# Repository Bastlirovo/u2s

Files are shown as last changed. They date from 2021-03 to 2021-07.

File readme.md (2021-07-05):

# USB To Serial Convertor Board

<p align="center">
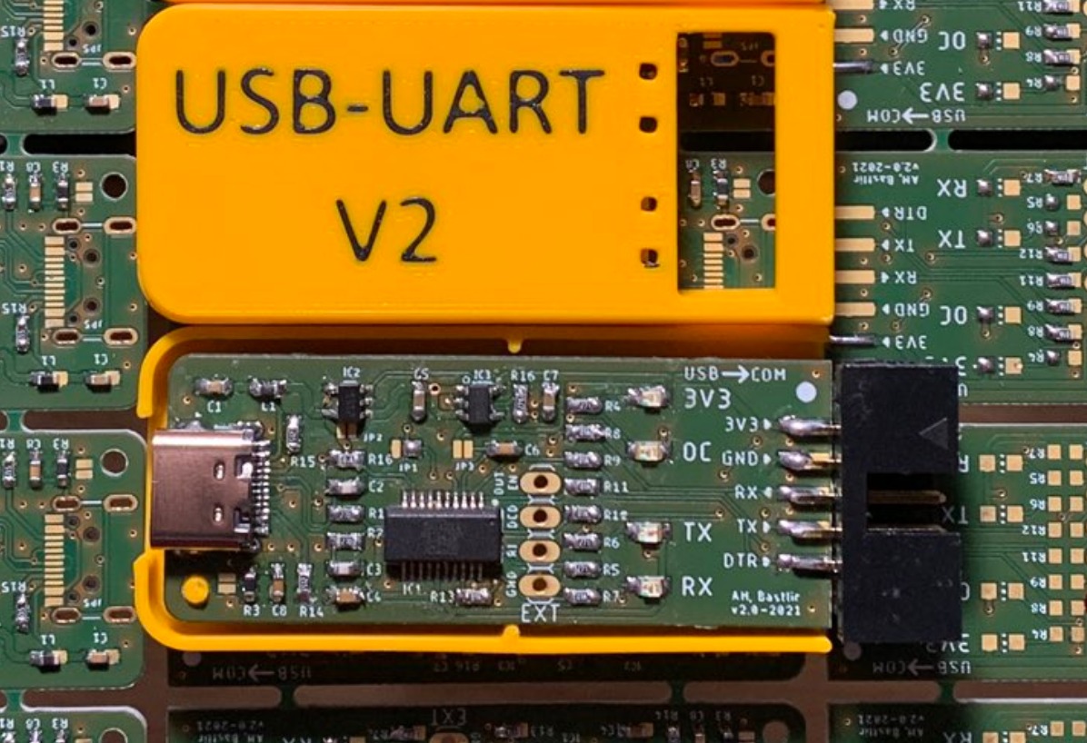
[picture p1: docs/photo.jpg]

</p>

## Features

- Reliable (no CH340 or FTDI232RL clones)
- 3V3 logic but 5V tolerant (no switching needed)
- On board 3V3 regulator (500 mA)
- Over current protection (suitable for development)
- Connector with key (so you can make idiot-proof cables) but DuPont friendly
- Both micro and USB-C connector (they are on opposite side of the board so you cannot use both in same time, but you will have more probability to find correct cable… you know Murphys Law)

## Connector

<p align="center">

</p>

| Pin | Dir. | Description |
|:---:|:----:| ---|
| 1 |  | 3.3 V output (max 500 mA)¹ |
| 2 | OUT | Tx Data Enable² |
| 3 |  | GND |
| 4 |  | 5 V output (max 500 mA)¹ |
| 5 | IN | Rx |
| 6 | IN | DSR |
| 7 | OUT | Tx |
| 8 | IN | CTS |
| 9 | OUT | DTR |
| 10 | OUT | RTS |

¹ 500 mA is total maximum for 5 V  and 3.3 V output.

² Indicate transition for half-duplex communication (e.g. for RS-485).

## PCB

- [Schematics](https://raw.githubusercontent.com/Bastlirovo/u2s/master/docs/usb-to-serial.png) ([PDF](https://raw.githubusercontent.com/Bastlirovo/u2s/master/docs/usb-to-serial.pdf))
- [Sources for Eagle CAD](pcb)
- **[Interactive BOM v1](https://ah01.github.io/u2s/ibom/ibom.html)** ([what is this](https://forums.autodesk.com/t5/eagle-forum/interactive-bom-for-eagle/td-p/8291710))

<p align="center">
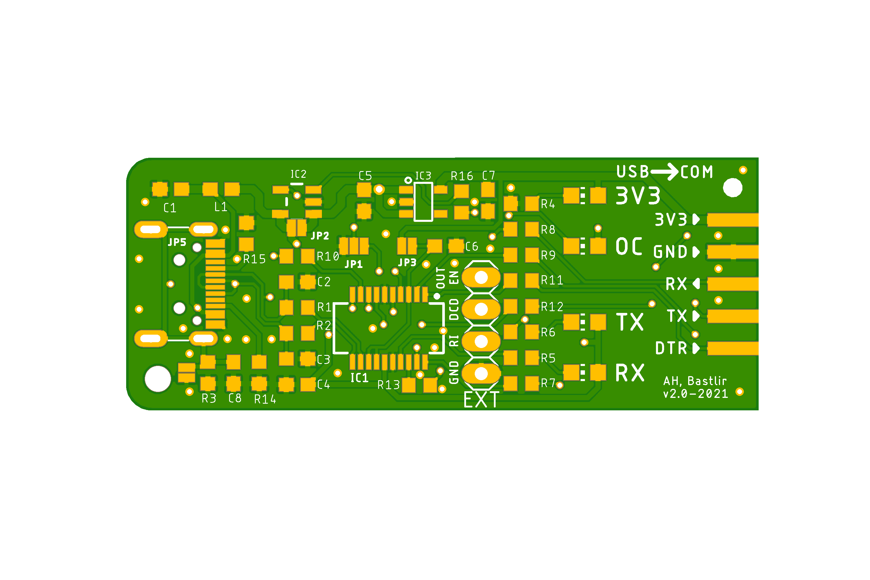
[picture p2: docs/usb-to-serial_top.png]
 &nbsp; &nbsp;
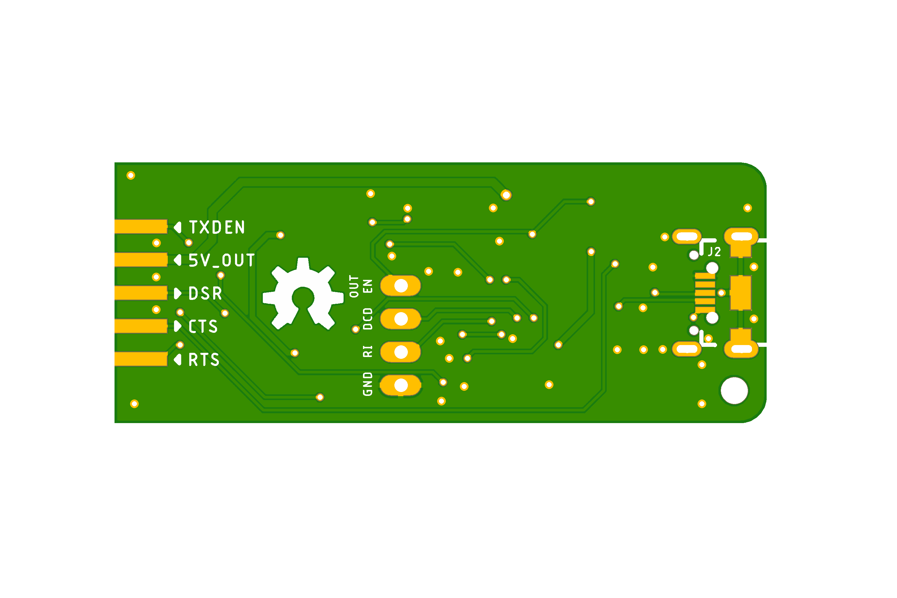
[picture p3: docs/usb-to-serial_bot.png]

</p>

## FTDI Template

For all PIN and LED functionality you need to configure FT231XS converter. There is template for [FT Prog](https://www.ftdichip.com/Support/Utilities.htm#FT_PROG) in [ft_prog directory](ft_prog).

## Credits

- [OK2UQL](https://twitter.com/ok2uqlGabo) - Case for 3D printing (see [tweet for example](https://twitter.com/ok2uqlGabo/status/1366835820972376068))
- [Bastlir](https://twitter.com/bastlir) - Update of design to v2 - mini->USB-C connector, OverCurrent LED, other minor updates based on found issues

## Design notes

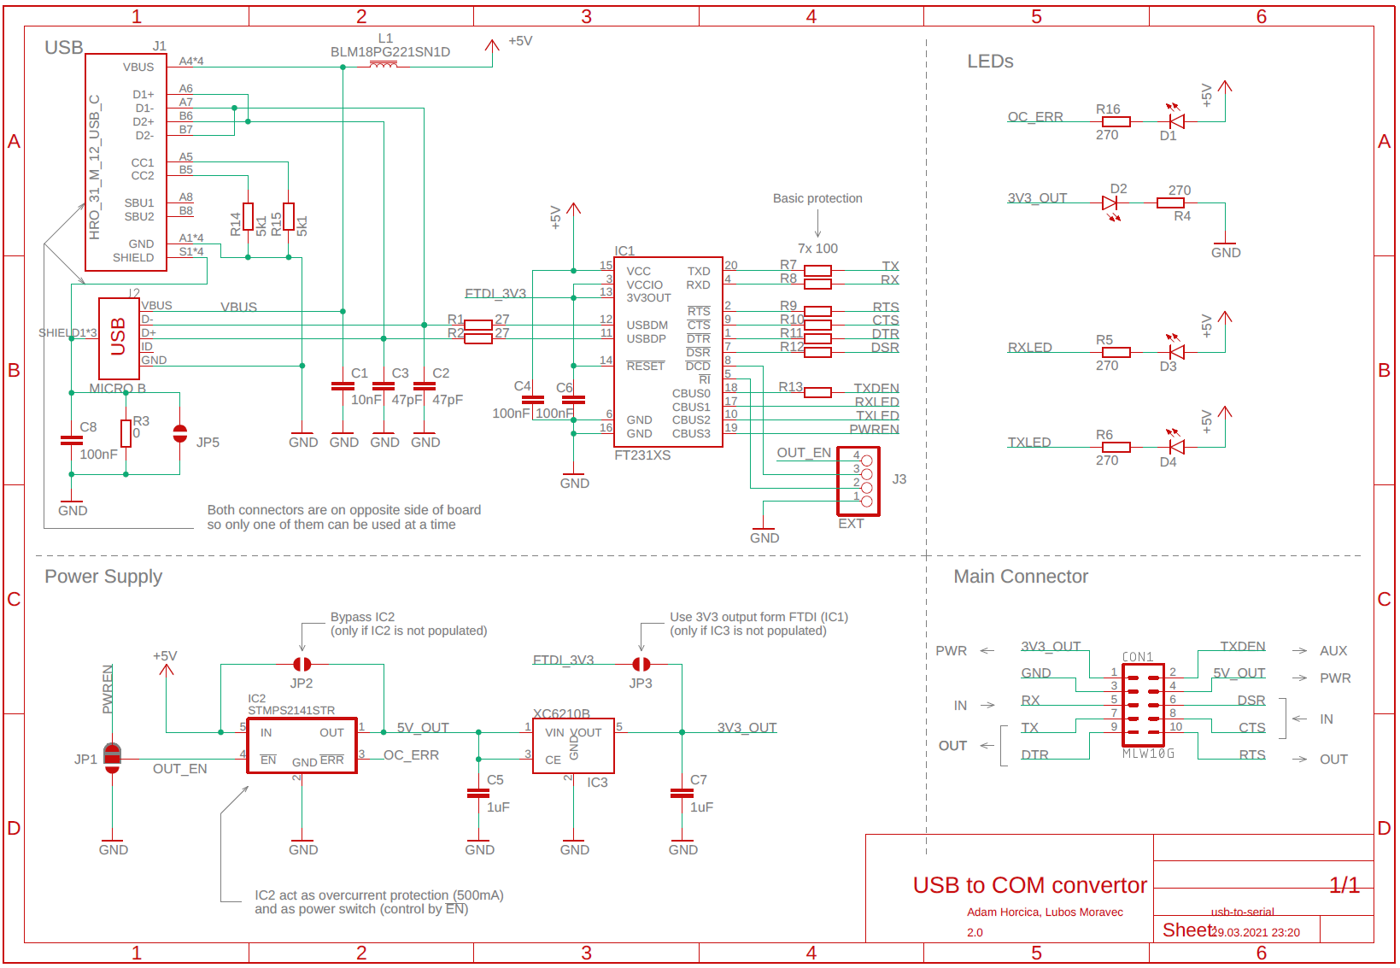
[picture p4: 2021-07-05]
docs/usb-to-serial.png

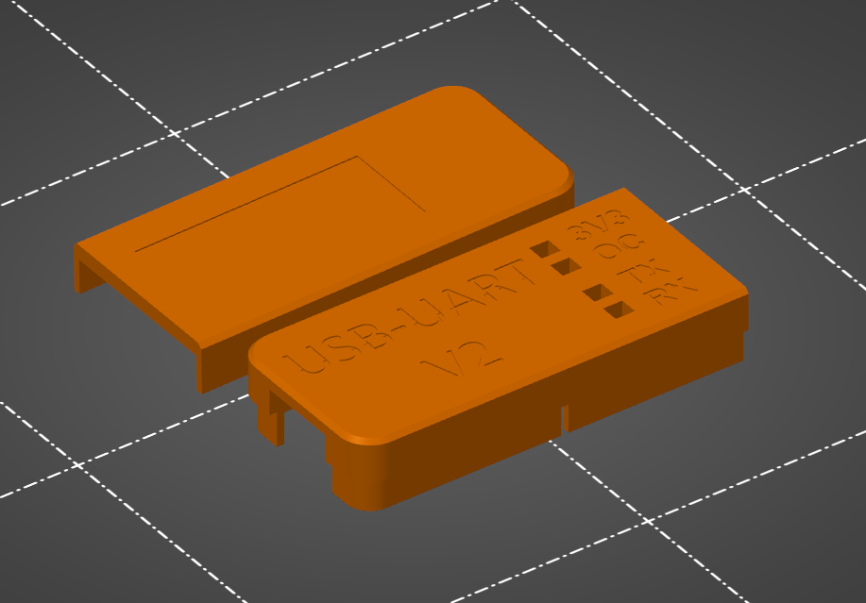
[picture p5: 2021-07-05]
3Dcase/v2/Case_no_hole/Case_no_hole.png

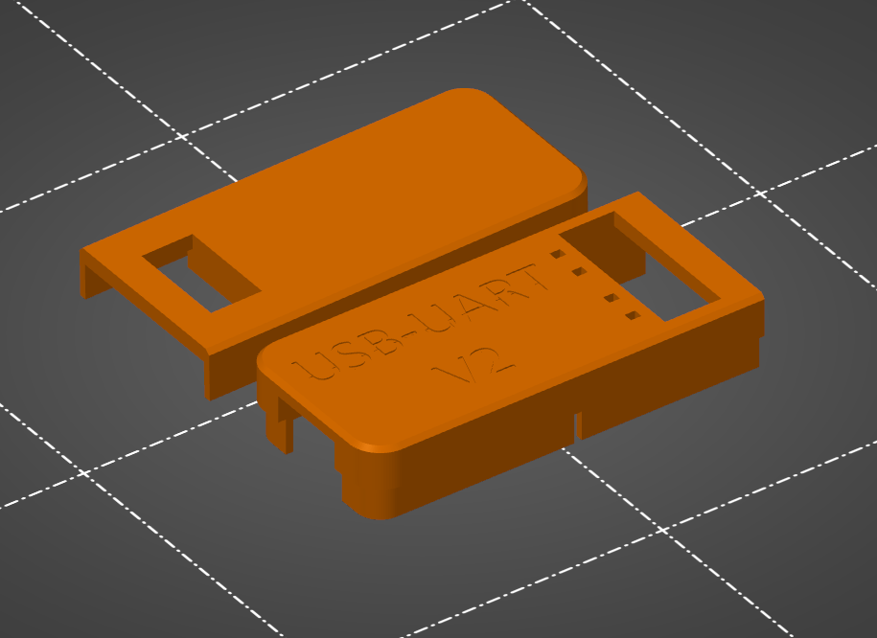
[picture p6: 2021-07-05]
3Dcase/v2/Case_with_holes/Case_with_holes.png

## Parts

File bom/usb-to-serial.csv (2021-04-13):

Qty | Value | Device | Package | Parts | Description | OC_FARNELL | OC_GME | ON_FARNELL | POPULARITY | PROD_ID | SPICEPREFIX | URL | VALUE | PRICE
4 |  | LEDCHIP-LED0805 | CHIP-LED0805 | D1, D2, D3, D4 | LED |  |  |  | 68 |  |  | https://cz.farnell.com/kingbright/kp-2012lsgc/led-green-0-8mcd-568nm-smd/dp/2463991 |  | 16,00 Kè
7 | 100 | R-EU_R0603 | R0603 | R7, R8, R9, R10, R11, R12, R13 | RESISTOR, European symbol |  |  |  | 70 |  | R | https://cz.farnell.com/multicomp/mcwr06x1000ftl/res-100r-1-0-1w-0603-thick-film/dp/2447227 |  | 0,91 Kè
3 | 100nF | C-EUC0603 | C0603 | C4, C6, C8 | CAPACITOR, European symbol |  |  |  | 73 |  | C | https://cz.farnell.com/kemet/c0603c104m4ractu/cap-0-1-f-16v-20-x7r-0603/dp/2581045 |  | 0,99 Kè
1 | 10nF | C-EUC0603 | C0603 | C1 | CAPACITOR, European symbol |  |  |  | 73 |  | C | https://cz.farnell.com/walsin/0603b103k500ct/cap-0-01-f-50v-10-x7r-0603/dp/2496828 |  | 0,44 Kè
2 | 1uF | C-EUC0603 | C0603 | C5, C7 | CAPACITOR, European symbol |  |  |  | 73 |  | C | https://cz.farnell.com/samsung-electro-mechanics/cl10a105ka8nnnc/cap-1uf-25v-mlcc-0603/dp/3013382 |  | 1,24 Kè
2 | 27 | R-EU_R0603 | R0603 | R1, R2 | RESISTOR, European symbol |  |  |  | 70 |  | R | https://cz.farnell.com/multicomp/mcwr06x27r0ftl/res-27r-1-0-1w-0603-thick-film/dp/2447316 |  | 0,32 Kè
4 | 270 | R-EU_R0603 | R0603 | R4, R5, R6, R16 | RESISTOR, European symbol |  |  |  | 70 |  | R | https://cz.farnell.com/multicomp/mcwr06x2700ftl/res-270r-1-0-1w-thick-film/dp/2447314 |  | 0,56 Kè
2 | 47pF | C-EUC0603 | C0603 | C2, C3 | CAPACITOR, European symbol |  |  |  | 73 |  | C | https://cz.farnell.com/yageo/cc0603jrnpo9bn470/cap-47pf-50v-5-c0g-np0-0603/dp/722042 |  | 1,30 Kè
2 | 5k1 | R-EU_R0603 | R0603 | R14, R15 | RESISTOR, European symbol |  |  |  | 70 |  | R | https://cz.farnell.com/multicomp/mcwr06x5101ftl/res-5k1-1-0-1w-0603-thick-film/dp/2447404 |  | 0,30 Kè
2 | BLM18PG221SN1D | FERRITE_BEAD-0603 | 603 | L1, R3 | Ferrite Bead (blocks, cores, rings, chokes, etc.) | 1515740 |  | BLM18PG221SN1D |  | NDUC-07859 |  | https://cz.farnell.com/murata/blm18pg221sn1d/ferrite-bead-0-1ohm-1-4a-0603/dp/1515740 |  | 1,60 Kè
1 | FT231XS | FT231XS | SSOP20_L | IC1 | FTDI FT231X Full Speed USB to Full-handshake UART |  |  |  |  | IC-11524 |  | https://cz.farnell.com/ftdi/ft231xs/i-f-usb2-0-fs-to-f-l-h-s-uart/dp/2081328 |  | 57,99 Kè
1 | HRO_31_M_12_USB_C | HRO_31_M_12_USB_C | HRO_31_M_12_USB_C | J1 | USB Shielded I/O Receptacle; Type C; Right Angle; Surface Mount; Gold over Nickel |  |  |  |  |  |  | https://lcsc.com/product-detail/USB-Connectors_Korean-Hroparts-Elec-TYPE-C-31-M-12_C165948.html |  | 10,00 Kè
1 | MICRO B | USB_MICRO-B_FEMALE-SMT | USB-B-MICRO-SMD | J2 | USB Type Micro-B Connector |  |  |  |  | CONN-11752 |  | https://cz.farnell.com/amphenol-icc-fci/10104110-0001lf/micro-usb-2-0-type-b-receptacle/dp/2293753 |  | 13,91 Kè
1 | MLW10G | MLW10G | MLW10G | CON1 | Connector Konektor 2,54mm, 2x5 |  | 800-035 |  |  |  |  | https://cz.farnell.com/multicomp/mc-254-10-00-st-dip/connector-header-10pos-2row-2/dp/2843527 |  | 4,52 Kè
1 | STMPS2141STR | STMPS2141STR | SOT23-5 | IC2 |  |  |  |  |  |  |  | https://cz.farnell.com/stmicroelectronics/stmps2151str/power-switch-1ch-500ma-sot23-5/dp/1842616 |  | 7,32 Kè
1 | XC6210B332MR | XC6210 | SOT-23-5 | IC3 |  |  |  |  |  |  |  | https://cz.farnell.com/torex/xc6210b332mr/ic-v-reg-cmos-ldo-3-3v-smd-6210/dp/1057803 |  | 17,64 Kè

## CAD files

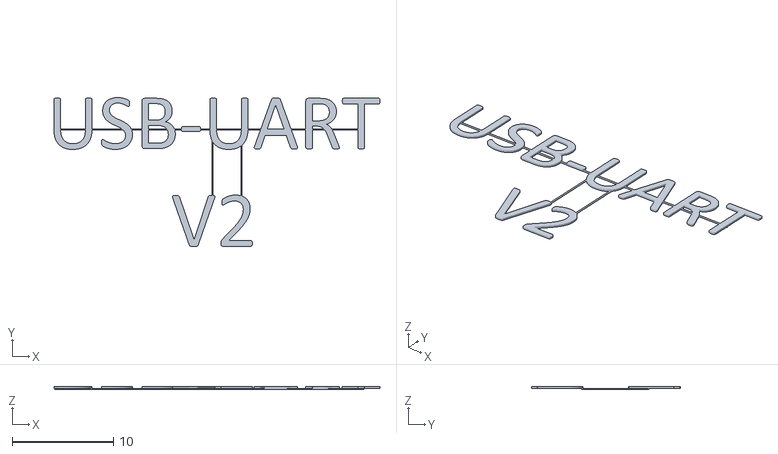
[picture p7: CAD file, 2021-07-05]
3Dcase/v2/Case_with_holes/Case_u2sV2_1_letters.stl
32.1 x 14.7 x 0.3

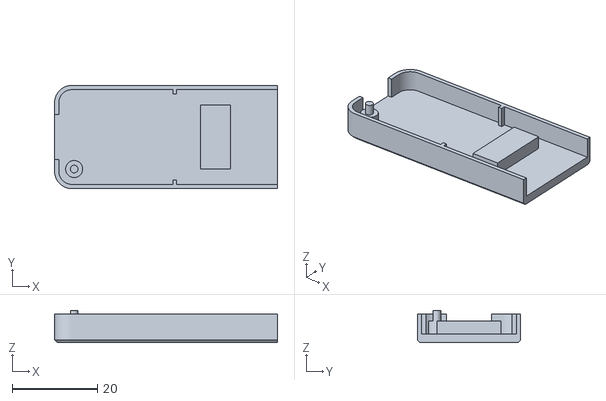
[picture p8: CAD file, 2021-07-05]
3Dcase/v2/Case_no_hole/Case_u2sV2_2.stl
52.2 x 24.2 x 7.50

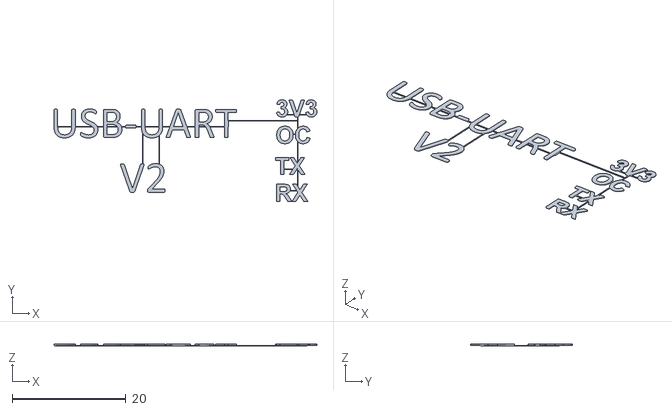
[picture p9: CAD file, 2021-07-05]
3Dcase/v2/Case_no_hole/Case_u2sV2_1_letters.stl
46.2 x 17.9 x 0.3

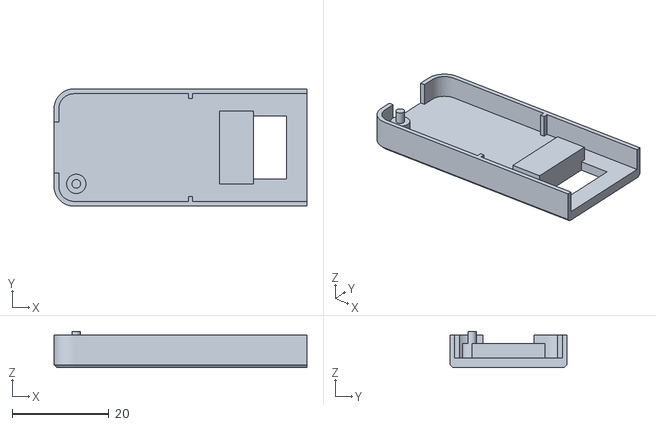
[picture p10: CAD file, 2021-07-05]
3Dcase/v2/Case_with_holes/Case_u2sV2_2.stl
52.2 x 24.2 x 7.50

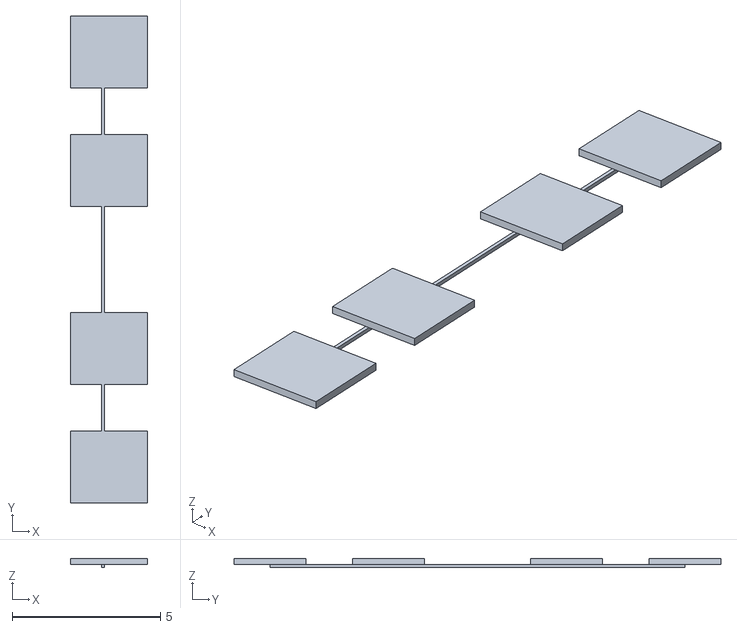
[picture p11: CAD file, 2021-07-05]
3Dcase/v2/Case_no_hole/Case_u2sV2_1_LED.stl
2.60 x 16.4 x 0.3

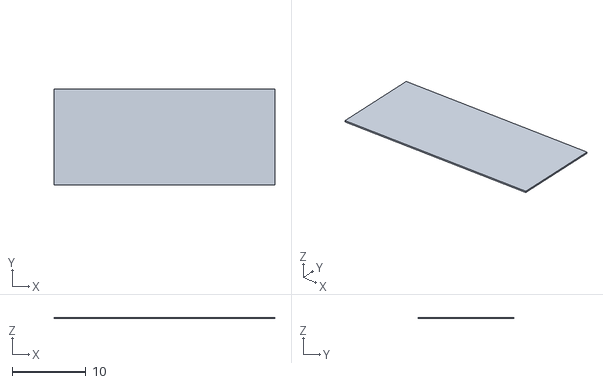
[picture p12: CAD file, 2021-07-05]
3Dcase/v2/Case_no_hole/Case_u2sV2_2_writebox.stl
30.0 x 13.0 x 0.2

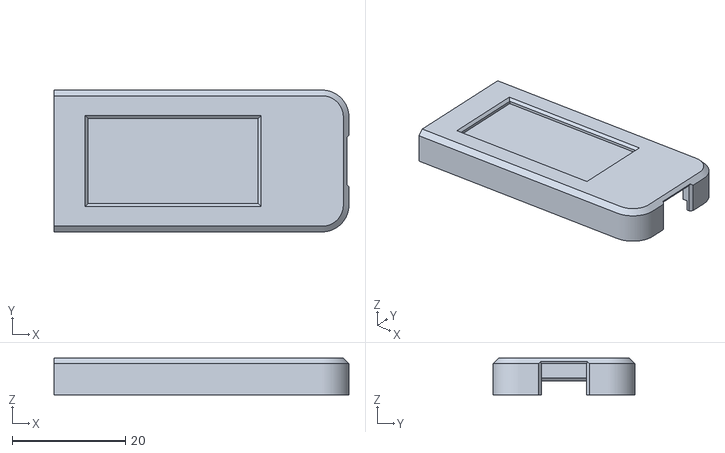
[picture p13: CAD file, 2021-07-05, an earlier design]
3Dcase/v1/UART2.stl
52.0 x 25.0 x 6.50

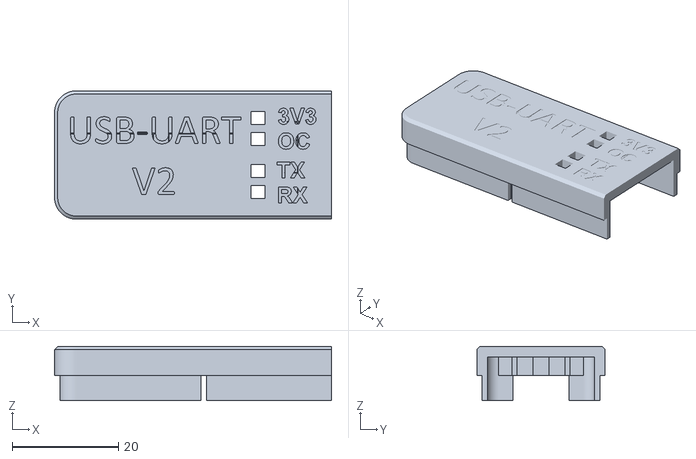
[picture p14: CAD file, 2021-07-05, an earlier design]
3Dcase/v2/Case_no_hole/Case_u2sV2_1.stl
52.2 x 24.2 x 10.2

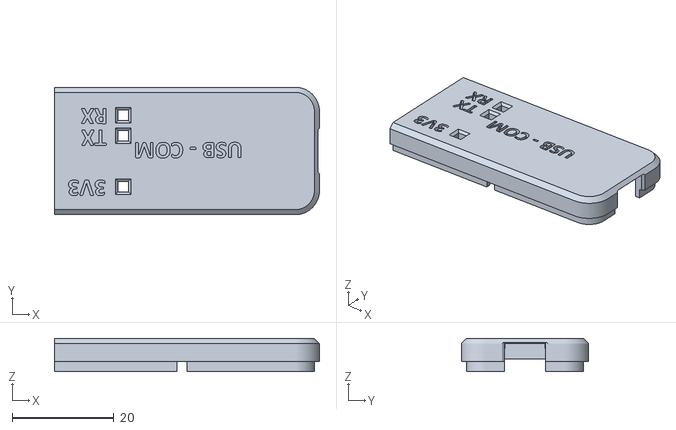
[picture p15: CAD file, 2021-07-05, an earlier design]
3Dcase/v1/UART1.stl
52.0 x 25.0 x 6.50

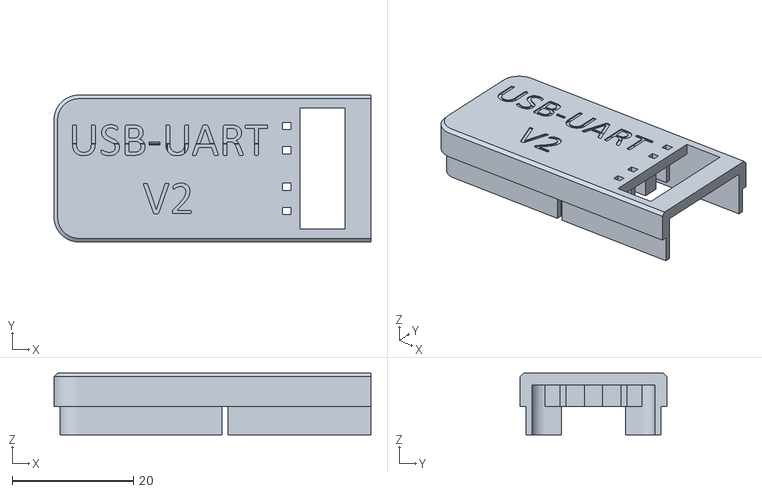
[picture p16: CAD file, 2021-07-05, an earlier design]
3Dcase/v2/Case_with_holes/Case_u2sV2_1.stl
52.2 x 24.2 x 10.2

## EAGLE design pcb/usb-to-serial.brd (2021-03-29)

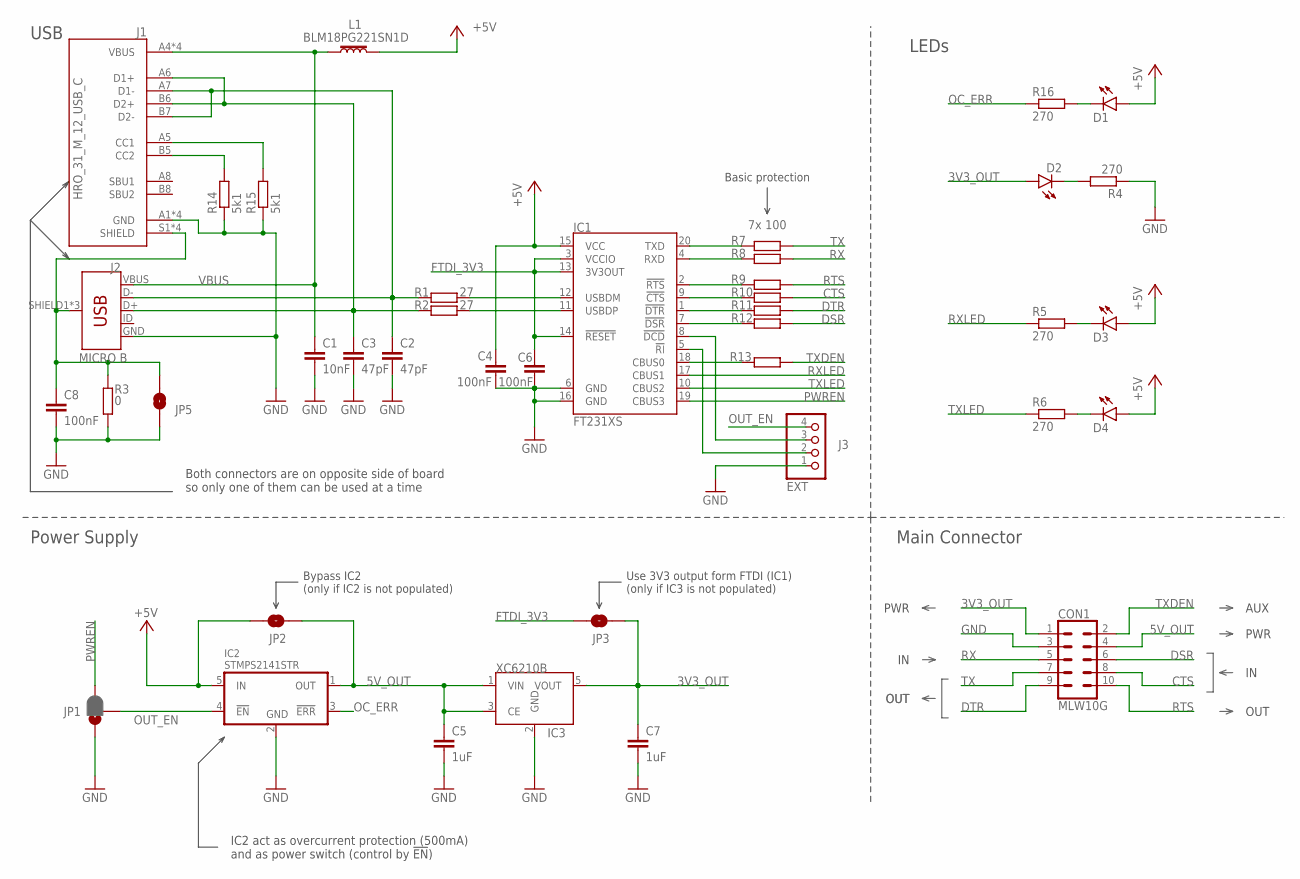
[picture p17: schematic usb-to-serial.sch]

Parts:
C1: 10nF; C0603
C2, C3: 47pF; C0603
C4, C6, C8: 100nF; C0603
C5, C7: 1uF; C0603
CON1: MLW10G
D1, D2, D3, D4: LEDCHIP-LED0805; CHIP-LED0805
EXT: J3; 1X04
IC1: FT231XS; SSOP20_L
IC2: STMPS2141STR; SOT23-5
IC3: XC6210B332MR; SOT-23-5
J1: HRO_31_M_12_USB_C
J2: MICRO B; USB-B-MICRO-SMD
JP1: JUMPER-SMT_3_1-NC_PASTE_NO-SILK; SMT-JUMPER_3_1-NC_PASTE_NO-SILK
JP2, JP3, JP5: JUMPER-SMT_2_NO_NO-SILK; SMT-JUMPER_2_NO_NO-SILK
L1: BLM18PG221SN1D; 0603
R1, R2: 27; R0603
R3: 0; R0603
R4, R5, R6, R16: 270; R0603
R7, R8, R9, R10, R11, R12, R13: 100; R0603
R14, R15: 5k1; R0603

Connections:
3V3_OUT: C7.1, CON1.1, D2.A, IC3.5 (VOUT), JP3.2
5V_OUT: C5.1, CON1.4, IC2.1 (OUT), IC3.1 (VIN), IC3.3 (CE), JP2.2
+5V: C4.1, D1.A, D3.A, D4.A, IC1.15 (VCC), IC2.5 (IN), JP2.1, L1.1
CTS: CON1.8, R10.2
DCD: EXT.3, IC1.8 (!DCD)
DSR: CON1.6, R12.2
DTR: CON1.9, R11.2
FTDI_3V3: C6.1, IC1.3 (VCCIO), IC1.13 (3V3OUT), IC1.14 (!RESET), JP3.1
GND: C1.2, C2.2, C3.2, C4.2, C5.2, C6.2, C7.2, C8.2, CON1.3, EXT.1, IC1.6 (GND), IC1.16 (GND), IC2.2 (GND), IC3.2 (GND), J1.A1 (GND), J1.A12 (GND), J1.B1 (GND), J1.B12 (GND), J2.GND, JP1.1, JP5.1, R3.1, R4.1, R14.1, R15.1
unnamed: IC1.18 (CBUS0), R13.1
unnamed: J1.A5 (CC1), R15.2
unnamed: IC1.20 (TXD), R7.1
unnamed: D2.C, R4.2
unnamed: J1.B5 (CC2), R14.2
unnamed: C8.1, J1.S1 (SHIELD), J1.S2 (SHIELD), J1.S3 (SHIELD), J1.S4 (SHIELD), J2.SHIELD1 (SHIELD), J2.SHIELD2 (SHIELD), J2.SHIELD3 (SHIELD), JP5.2, R3.2
unnamed: D3.C, R5.2
unnamed: D4.C, R6.2
unnamed: D1.C, R16.2
unnamed: IC1.4 (RXD), R8.1
unnamed: IC1.2 (!RTS), R9.1
unnamed: IC1.9 (!CTS), R10.1
unnamed: IC1.1 (!DTR), R11.1
unnamed: IC1.7 (!DSR), R12.1
OC_ERR: IC2.3 (!ERR), R16.1
OUT_EN: EXT.4, IC2.4 (!EN), JP1.2
PWREN: IC1.19 (CBUS3), JP1.3
RI: EXT.2, IC1.5 (!RI)
RTS: CON1.10, R9.2
RX: CON1.5, R8.2
RXLED: IC1.17 (CBUS1), R5.1
TX: CON1.7, R7.2
TXDEN: CON1.2, R13.2
TXLED: IC1.10 (CBUS2), R6.1
USBD2_N: IC1.12 (USBDM), R1.2
USBD2_P: IC1.11 (USBDP), R2.2
USBD_N: C2.1, J1.A7 (D1-), J1.B7 (D2-), J2.D-, R1.1
USBD_P: C3.1, J1.A6 (D1+), J1.B6 (D2+), J2.D+, R2.1
VBUS: C1.1, J1.A4 (VBUS), J1.A9 (VBUS), J1.B4 (VBUS), J1.B9 (VBUS), J2.VBUS, L1.2

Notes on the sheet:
USB
LEDs
Main Connector
Power Supply
Use 3V3 output form FTDI (IC1) (only if IC3 is not populated)
Both connectors are on opposite side of board so only one of them can be used at a time
7x 100
Bypass IC2 (only if IC2 is not populated)
OUT
PWR
AUX
Basic protection
IC2 act as overcurrent protection (500mA) and as power switch (control by !EN!)

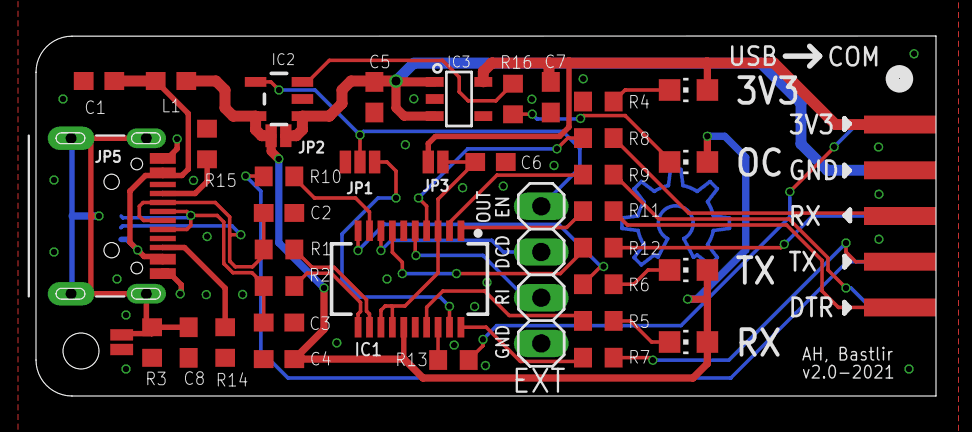
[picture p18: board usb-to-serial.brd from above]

Board: 2 copper layers, 50.0 x 20.0 mm, 40 parts (1 on the bottom side), 38 nets.

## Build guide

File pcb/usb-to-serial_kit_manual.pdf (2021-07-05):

Plan n. | Qty | Value | Parts
| 4 | | D1, D2, D3, D4
1 | 2 | 27 | R1, R2
2 | 7 | 100 | R7, R8, R9, R10, R11, R12, R13
3 | 4 | 270/1k8 | R4, R5, R6, R16
4 | 2 | 5k1 | R14, R15
5 | 2 | 47pF | C2, C3
6 | 1 | 10nF | C1
7 | 3 | 100nF | C4, C6, C8
8 | 2 | 1uF | C5, C7
9 | 2 | BLM18PG221SN1D | L1, R3
10 | 1 | FT231XS | IC1
11 | 1 | STMPS2141STR | IC2
12 | 1 | XC6210B332MR | IC3
13 | 1 | HRO_31_M_12_USB_C | J1
14 | 1 | MICRO B | J2
15 | 1 | MLW10G | CON1

If you will use all components, connect JP1 in position visible below. LED 3V3 + R4
LED OC + R16
LED TX + R6
LED RX + R5
All files are available on: https://github.com/Bastlirovo/u2s , original v1 repo https://github.com/ah01/u2s

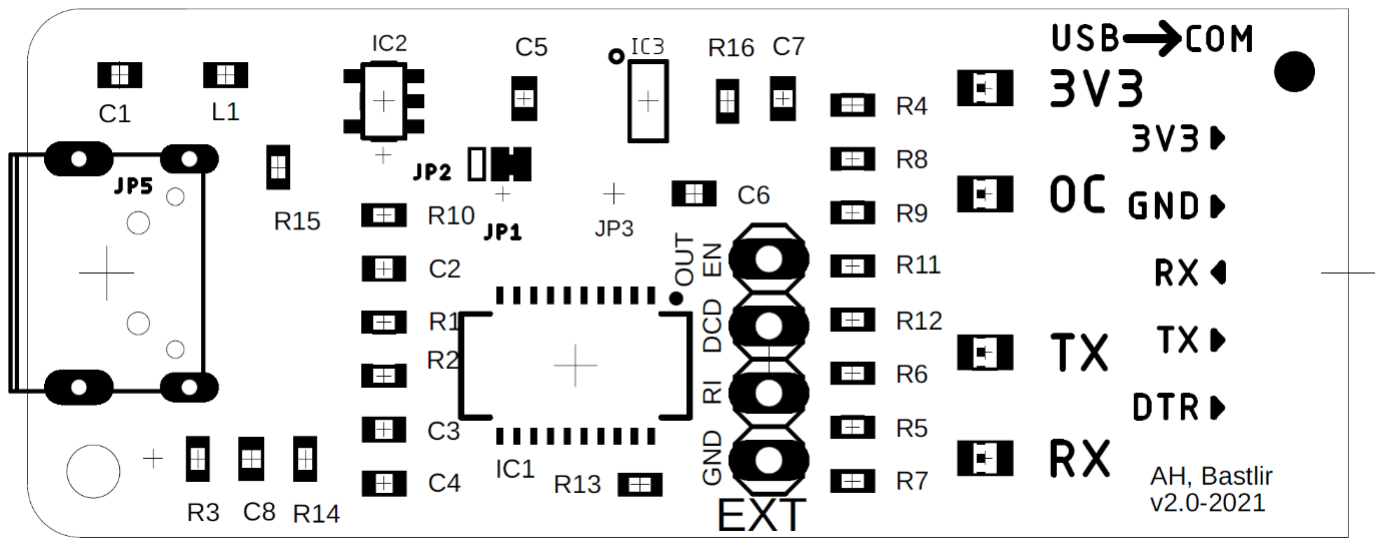
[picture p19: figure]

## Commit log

2021-03-26 Update to v2
    Changes from Issues:
    - Pinout on top/bottom silkscreen
    - Add indication LED to error output of IC2 (over current shutdown)
    - Add EN pin of IC2 to EXT connector
    - Add OSHW logo to silkscreen
    Replace mini USB connector with USB-C
    - Replace IC3 with XC6210
    [usb-to-serial.brd, usb-to-serial.sch]
2021-03-29 Polishing of v2 according to notes from Adam, added schematic in PDF, gerber ZIP package.
    [usb-to-serial.brd, usb-to-serial.sch]
2021-04-13 Update of BOM for v2 with Farnell links and prices
    [usb-to-serial.csv]
2021-07-05 3D models added, update of Readme and kit manual for v2.
    [Case_u2sV2_1.stl, Case_u2sV2_1_LED.stl, Case_u2sV2_1_letters.stl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]

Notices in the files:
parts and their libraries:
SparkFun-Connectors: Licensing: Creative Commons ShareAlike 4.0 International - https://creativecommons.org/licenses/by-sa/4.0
